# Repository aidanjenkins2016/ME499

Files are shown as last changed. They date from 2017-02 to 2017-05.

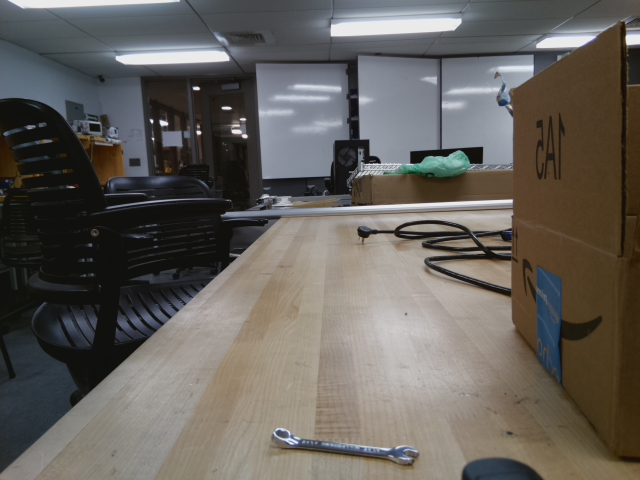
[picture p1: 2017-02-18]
Image Processing Test/output.jpg

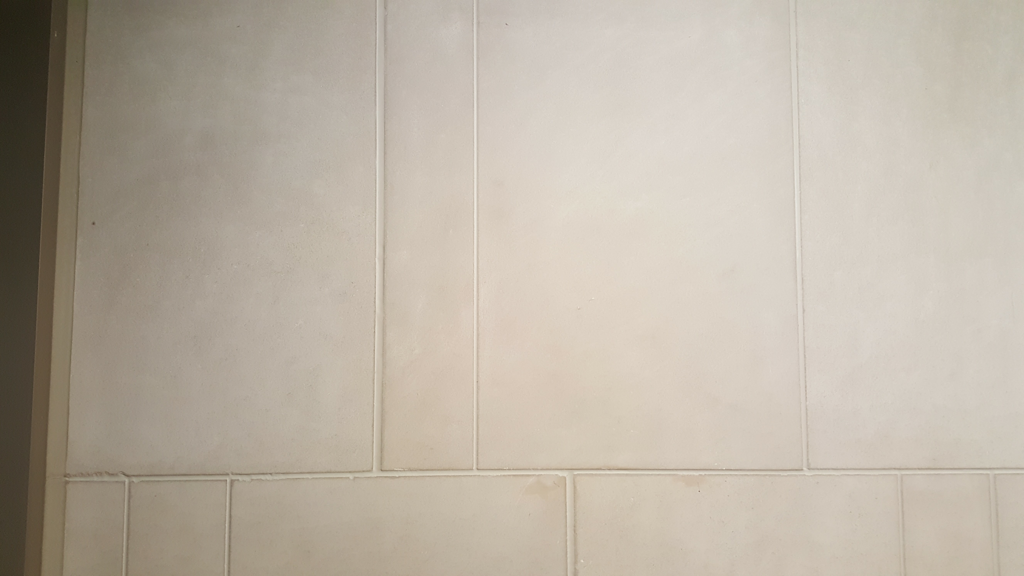
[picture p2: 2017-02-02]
Test Images/20170127_183603.jpg

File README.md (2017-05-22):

# ME499: Exploring Autonomous Vehicles
Repo for our ME499 Exploring Autonomous Vehicles Project

The bulk of this repo contains files for our computer vision project. This projects relies on a 1:10 scale RC buggy outfitted with a Raspberry Pi 3B and Pi camera for navigating hallways. We seek to build on our prior expereince with autonmous driving, using GPS and compass data, by exploring computer vision and machine learning algorithms.

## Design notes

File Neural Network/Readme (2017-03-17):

The neural network code is found here. The Doge_Net code is a test implementation that attempts to identify dogs and cats. This allows for development and debugging since we currently do not have training data for the Tech Hallways.

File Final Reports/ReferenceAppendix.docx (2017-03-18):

Reference Appendix:

Included are relevant links for understanding these topics

- Setting up Raspberry Pi WiFi and SSH
  - https://www.raspberrypi.org/documentation/configuration/wireless/wireless-cli.md
  - https://www.raspberrypi.org/documentation/remote-access/ssh/
- Connecting Raspberry Pi to an enterprise network similar to Northwestern’s
  - https://www.raspberrypi.org/forums/viewtopic.php?f=36&t=44029
  - https://www.raspberrypi.org/forums/viewtopic.php?f=36&t=111100
- Cloning Raspberry Pi SD cards
  - http://lifehacker.com/how-to-clone-your-raspberry-pi-sd-card-for-super-easy-r-1261113524
- GitHub command line tutorial
  - http://product.hubspot.com/blog/git-and-github-tutorial-for-beginners
- MIT self driving car open lecture
  - http://selfdrivingcars.mit.edu/
- Udacity self driving car project
  - https://medium.com/udacity/were-building-an-open-source-self-driving-car-ac3e973cd163#.qa2c8v8vr
  - https://github.com/udacity/self-driving-car
- Arduino serial communications
  - http://www.ladyada.net/learn/arduino/lesson4.html
  - https://oscarliang.com/connect-raspberry-pi-and-arduino-usb-cable/
  - https://oscarliang.com/raspberry-pi-and-arduino-connected-serial-gpio/
  - http://www.seeed.cc/project_detail.html?id=168
- Python and OpenCV
  - http://www.pyimagesearch.com/
- http://docs.opencv.org/2.4/doc/tutorials/imgproc/imgtrans/canny_detector/canny_detector.html
- http://docs.opencv.org/trunk/d7/d8b/tutorial_py_face_detection.html
- https://pythonprogramming.net/haar-cascade-face-eye-detection-python-opencv-tutorial/
- Ubuntu
  - http://www.pyimagesearch.com/2015/07/20/install-opencv-3-0-and-python-3-4-on-ubuntu/
- Mac
  - http://www.pyimagesearch.com/2015/06/15/install-opencv-3-0-and-python-2-7-on-osx/
- Raspberry Pi
  - http://www.pyimagesearch.com/2016/04/18/install-guide-raspberry-pi-3-raspbian-jessie-opencv-3/
- Research and Neural Networks
  - http://blog.davidsingleton.org/nnrccar/
  - https://www.youtube.com/watch?v=O8BXapqL5lA
  - https://github.com/hamuchiwa/AutoRCCar

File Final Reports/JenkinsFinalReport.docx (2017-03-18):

Aidan Jenkins

March 17, 2017

ME499

Autonomous Vehicle 499: Winter 2017

Advisor: Nick Marchuk

Introduction

This second quarter of work on the autonomous vehicle project was completed with Ryan Yu and we sought to expand on lessons learned from Fall 2016 and investigate more popular and sophisticated technologies. In this stage of the project computer vision and machine learning technologies were explored. The goal of the project was to have the car navigate the main loop on the second floor of the Technological Institute at Northwestern University (Tech). This was selected because of its proximity to the Mechatronics Lab in the Ford building, its large hallways with distinct tile patterns, and absence of fire doors. A second chassis was acquired so work could be performed without dismantling the car from the Fall. An additional goal of this quarter’s project was to keep hardware costs down. Machine learning and computer vision algorithms are computationally expensive, however we wanted to maintain accessibility for this project, so popular hobby components were used. This report will document the steps taken this quarter, the reasons why, and offer suggestions for future efforts. Ryan and I wished to have a demonstration at the 2017 Chicago Maker Faire in April, however that event was cancelled in the second week of March.

Initial Steps

The first steps taken in this quarter of the project were to apply lessons learned from Fall 2016. Ryan and I spent the first week planning and getting a better understanding of project and what we thought it would take to complete it while being mindful of how it would fit in our schedules. The focus was on getting as much set up as possible the first half of the quarter so we could spend the rest tackling the unknowns, namely the neural network. We decided to make sure we found a location indoors to test in. Fall in Chicago was not particularly conducive to outdoor testing, particularly at the end of the quarter in December, Winter would not be any better. That is why we selected the second floor of Tech. It was safe from the elements and had regular and easily identifiable features on the floor, something we thought would be beneficial for line following and edge detection. The hallways are about 8 feet wide and form a square with over 100 feet per side. A photo of one of the hallways is shown in Figure 1. Moreover, after 7 pm the hallways were largely unoccupied so we would have ample time to test.

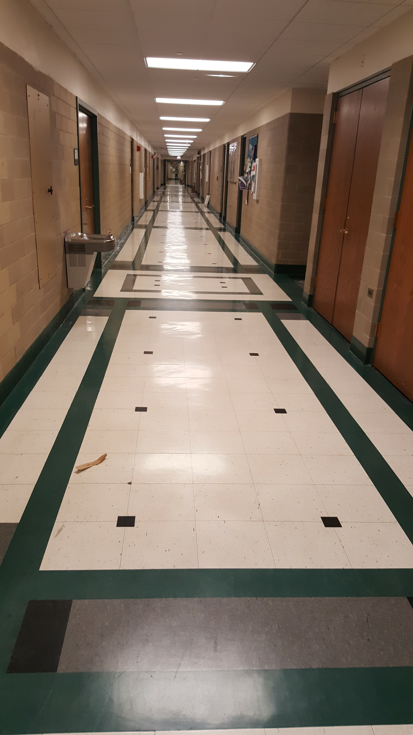
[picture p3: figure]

Figure 1 Proposed hallway for testing the car. Note linear arrangement of tiles on the floor that can be used for edge detection

Hardware selection was completed in parallel to planning, because scope and location was closely related to the quality of hardware needed. Because of the cost goals and familiarity with R/C hobby components from Fall 2016, so similar parts were used. This time a 1:10 scale buggy with 4-wheel drive was selected. Its increased ground clearance over a 1:10 “touring car” made it better suited to diving outside, or in inclement weather if we got to a point where we were testing outside. On the electronics side, hobby components, a 2.4 GHz Tx/Rx combo, brushless motor, electronic speed control (ESC), and servo were used. Similar to the Fall 2016 phase, these components were interfaced with a Teensy 3.6 microcontroller. A Raspberry Pi 3 B was selected to handle the computer vision and neural net calculations on board the car. This was the most up to date model of the Raspberry Pi featuring a 1.2GHz quad core processor, 1GB ram, and built-in wireless communication, and a dedicated graphics chip to accelerate graphics performance. This computer was selected, as opposed to a more purpose-built platform like the NVIDIA Jetson board, because of its widespread adoption, cost vs. performance, and open source support. Additionally, if the Pi had performance problems, it could stream images to a laptop or desktop.

Setup

To avoid late stage technology setbacks, we sought to set up our hardware to be tolerant to changes—we built in contingencies. One of the first orders of business was flashing a Linksys router with the open source dd-wrt firmware. This unlocks a lot of router features and would give us more options if we needed to use a server-client relationship to control the car.

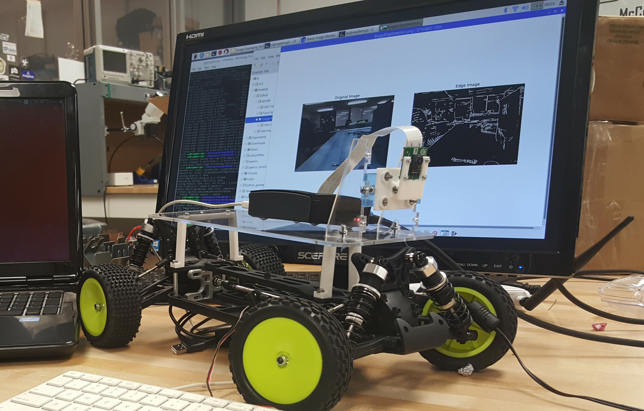
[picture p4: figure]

Figure 2 Buggy with image processing on display

The next objective was to install OpenCV, an open source image processing package. I attempted to install this in Windows 10, but this proved incredibly challenging. After two weeks of no progress, I decided I needed to move on. I created a 40GB partition on my hard drive, installed Ubuntu 16.04, and quickly installed the necessary software from the command line. Although Ubuntu can run with a lot less disk space, datasets for neural networks have gigabytes of data—it made more sense to have one larger partition than redo it later. To leverage my laptop’s graphics card for training the neural net later, I needed to install an NVIDIA driver. Initially I used the sudo apt-get command, this resulted in my computer booting, but not allowing me to log in. The latest NVIDIA driver for Linux operating systems should be downloaded from their website as a .tar file and installed.

Installing the Linux Raspbian OS on the Raspberry Pi was quickly accomplished using the New Out Of the Box (NOOBs) software from the Raspberry Pi Foundation. With Raspbian installed, downloading and installing OpenCV was trivial. For long term support and project stability Ryan installed Python virtual environments in Raspbian. This allowed us to run code using multiple versions of Python. This was important because although the newest version is Python 3.6, version 2.7 is still extremely popular and a lot of code that works on one will not work on the other. The baseline setup for hardware and software took approximately a week and a half longer than expected.

Progress

Once the software was installed, we immediately started testing OpenCV, the Pi Camera, and simply scripts in Python. We practiced operations like resizing and rotating images. To verify the install of OpenCV and better understand image processing techniques we did a “hello world” like activity with Haar cascades for face recognition. Additionally, because line following was of interest, we implemented a Canny edge detection algorithm to extract edge data from captured images. An example of an original image and an image with edge detection overlaid is shown in Figure 3. Preprocessing images is important for this project because it will greatly simplify the inputs to the neural network and lower the computation load. Eliminating “noise,” unneeded features, from the pictures before they are converted to numpy arrays allows the neural network to focus on classifying fewer elements from the images.

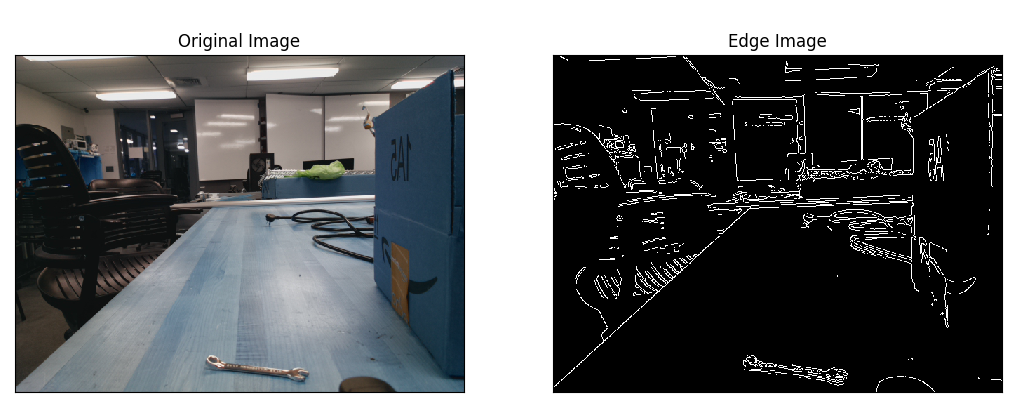
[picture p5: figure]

Figure 3 Original image captured from the Pi Camera mounted on the buggy and the Canny edge processed image

In order to get practice with neural networks, Ryan worked on a basic neural net that classified images as either containing a cat or dog. There are many ways to approach neural network design and it is difficult to understand what the exact outcome will be for the network design. This is one of the reasons why machine learning and neural networks are such popular fields, there is much more to be understood. We wanted our network to be supervised—take inputs classified by our training data code as an image paired with a steering angle and known as “good”. For a simple neural net implementation, we wanted to have an output layer with only a few nodes. In other words, for any given input, we wanted the neural net to return right, left, straight, or stop. Research into this type of implementation, however, suggested that it may not be sufficient. Information in lectures from MIT’s class 6.S094: Deep Learning for Self-Driving Cars and Udacity’s self-driving car project suggested we would need a Convolutional Neural Network

(CNN), or a Long Term-Short Term neural network to incorporate some history into the training of the model. As the amount of code and number of devices grew; four operating systems spread across three laptops and the two Raspberry Pi’s, we cloned the Pi SD cards for backup and created a GitHub repository. This way data losses would not hold us back and keep code consistent across devices. Furthermore, it allows this project to document itself, should anyone else like to work on something similar.

Conclusion

In the Fall portion of the project some parts of the code were hacked together in the last week of the quarter to make the car work. When problems arose, the code proved nearly impossible to debug. As the quarter drew to a close, we rapidly realized creating and implementing the neural network was more nuanced than we initially expected. Other courses had final projects that were taking more time away from the car project, so we focused on understanding neural networks better and how we are going to implement a more robust design in the spring instead of cobbling together something of poor quality.

The major remaining parts of the project are the data recording and classification code, building the neural network, and training the network. If the Pi cannot handle real time calculations it needs to be configured as a client that streams images to the laptop for classification and the laptop will return a steering value. The data recording code is straight forward in concept. When the car is driven in manual mode it will save images and the corresponding steering angle. When the neural network is trained, it will learn to identify the correct steering angle for what the camera is seeing. The Pi should be able to handle this using serial communication with the Teensy and storing data on its SD card, or an external USB drive. Udacity, for example, is using ROS, an open source platform for robotics, to manage the training data. This needs to be investigated as well as using a machine learning package. TensorFlow is very popular and will be much easier to use to create a CNN or a neural net with memory. Because of the difficulty of programming the more complicated neural nets in Python and the industry acceptance of TensorFlow, we strongly recommend considering it for the neural net creation. The large amount of data generated also poses a problem because of the amount of time needed to train the network. We believe the last component needed to make this project robust is creating a USB bootable version of Linux that can be run on a computer with a powerful graphics card that can accelerate training time from days to hours.

The goals originally defined for this phase of the project were ambitious and although they were not all completed, the project is better understood and well framed for success in the future. At this point, Ryan and I are very comfortable with finishing the remaining code needed to get our prototype working. Additionally, we will have more time to devote to the project. Ryan has finished taking classes and is doing some travelling. I am only enrolled in one class and working in the mechatronics lab. It would have been very satisfying to finish the project this quarter, however we are well set up for next quarter and are looking forward to completing the project the right way.

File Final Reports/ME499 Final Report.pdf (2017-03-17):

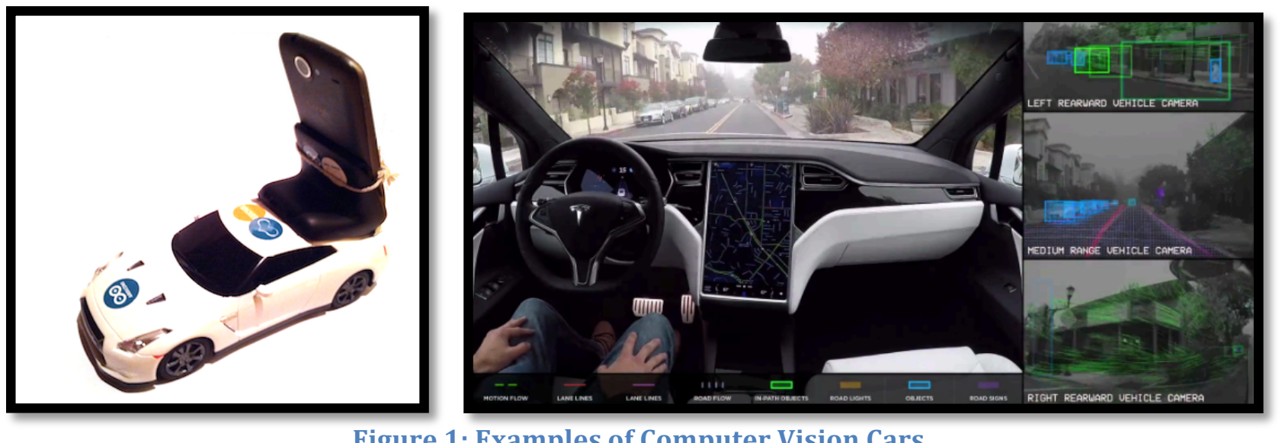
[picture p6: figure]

Yu 1

Siyuan Yu
ME499
Nick Marchuk

Building a Computer Vision Based Autonomous Vehicle

I. Abstract

This quarter, I worked with Aidan Jenkins to build a vehicle capable of computer vision based autonomous navigation. The main goals of this project were to learn how to use OpenCV, neural networks, the raspberry pi 3, and the pi camera in order to build an RC vehicle that could drive itself. Through the mistakes that were made and knowledge that was gained from the previous quarter, we managed to plan out our goals more realistically and meet the deadlines that we set out to achieve this quarter. Overall, we successfully downloaded and implemented OpenCV for image processing, began developing a neural network for computer vision learning, and built a custom RC car platform that can interface with the Raspberry Pi 3 and hold all of our electronics.

II. Goals and Planning

The main goal of this quarter’s project was to develop an RC vehicle capable of navigating through the hallways of tech autonomously using computer vision algorithms and a camera. From last quarter’s project, we learned that semi-autonomous navigation through GPS and IMU sensors was imprecise and not very robust. In addition, GPS navigation requires outdoor operation and does not work indoors. A computer vision approach is a much more elegant solution to this problem and has been successfully tested in projects done by students and by major companies such as Tesla and Google (see Research Appendix and Figure 1).

Figure 1: Examples of Computer Vision Cars
This computer vision approach involves combining image processing and machine learning techniques to train the vehicle to drive the way a human would by using primarily camera information. Although real autonomous vehicles rely on more than just cameras (sensor fusion from other sensors) and are based on sophisticated machine learning algorithms such as convolutional neural networks, we decided it would be interesting to see how effective a cheap Raspberry Pi based RC car can be using a standard feedforward neural network with back propagation.

After the poor scheduling of last quarter’s RC car project, one of the main focuses of this quarter was to develop a reasonable schedule and follow it as closely as possible (Figure 2). The intended goal for this quarter was to explore and develop all the hardware and software components needed to make an autonomous computer vision vehicle possible. This included downloading and learning OpenCV for image processing, learning how to use the Raspberry Pi 3 and the Pi camera, setting up our RC car to take Raspberry Pi controls, creating a neural network framework, and fabricating custom mounts for our electronics. Some of our reach goals included implementing all of our code on the Pi, training our vehicle, and testing the vehicle in tech. These goals were not met this quarter, but we have made plans to achieve these goals next quarter.

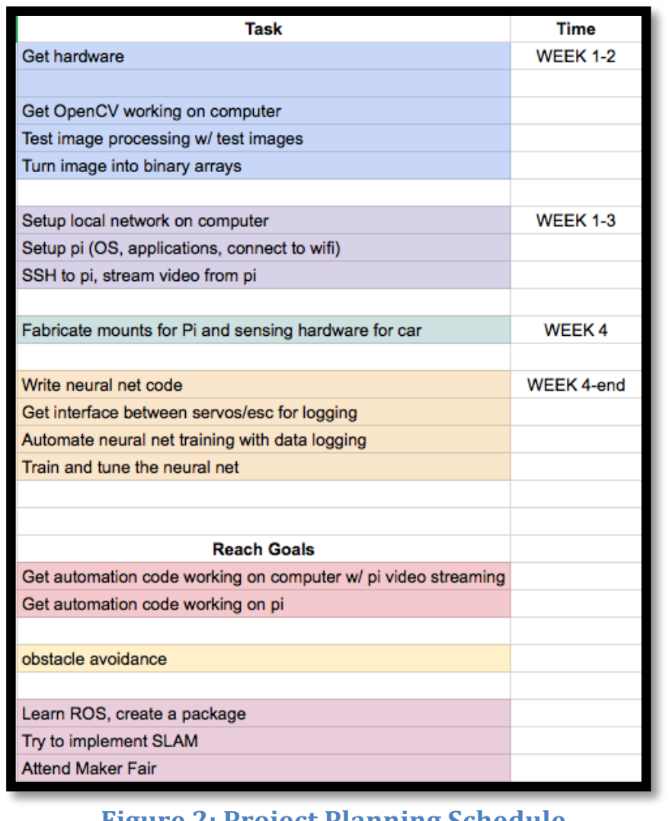
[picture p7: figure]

Figure 2: Project Planning Schedule

III. Hardware

i) RC Car

For the RC car, we decided to stick with the 4-wheel drive 1:10 scale buggy that was used in last quarter’s project. This car has great performance and adequate ground clearance for both outdoors and indoors use. In addition, the buggy has good mounting locations for our custom electronics platform. The buggy comes equipped with a 2.4 GHz TX/RX combo, an ESC, a brushless motor for throttle, and a servo for steering. Using the foundation we developed from last quarter’s project, a Teensy 3.6 is used to interface with the car’s ESC. The Teensy intercepts control inputs from either the Raspberry Pi or the RC controller and turns them into PWM inputs for the ESC (see Figure 3).

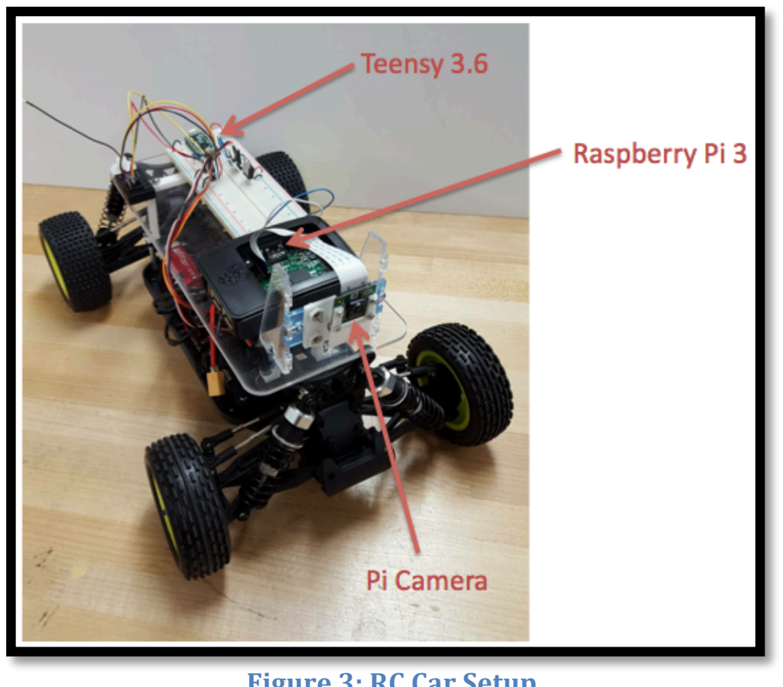
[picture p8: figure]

Figure 3: RC Car Setup
ii) Onboard Computer

We chose to use the new Raspberry Pi 3 B as our primary on board computer. We chose the Pi for its cheap price, compact size, dedicated graphics chip, and compatibility with a good selection of small but powerful camera hardware. In addition, there is lots of online support for Raspberry Pi projects (and specifically computer vision projects), which turned out to be extremely useful for us since we were first time users. Overall, the Pi directly interfaces with the camera and handles all of the image-processing and neural network computations. The Pi communicates with the Teensy using serial communication protocols and the Teensy is in charge of all the RC car control algorithms. All of this can technically be done on just the Raspberry Pi 3 alone, but due to time constraints and our previous work, we decided it would be easier for the Pi to output control commands and let the Teensy deal with the control signals.

iii) Electronics Platform

In order to hold all of these electronics, we lasercut a platform out of acrylic and 3D printed plastic supports that bolted onto the frame of the car. We also 3D printed an adjustable camera mount for the Pi camera at the front of the car. Since the camera is the only sensor that we have on the vehicle, it is extremely important that it is well mounted. It is also important that its height and angle are adjustable for distance calculations and field of view purposes.

iv) Router

In case the Raspberry Pi was not powerful enough to do the neural network computations onboard, we decided to flash a Linksys router and create a server-client network to facilitate streaming from the Pi to our laptops. This backup allows us to stream images from the Pi and perform the necessary computations on our laptops on the go. This type of streaming setup introduces delay into the system, but is a good backup to have in case all the computations cannot be performed onboard. This networks is also helpful for debugging and training purposes.

IV. Software

i) OpenCV

One of the most important goals of this project was to learn how to download, setup, and use the OpenCV library. OpenCV is an open source image-processing library that provides building blocks for computer vision projects such as image filters, machine learning dataset structures, and other useful image manipulation functions. In order to develop and debug more easily, we decided to download OpenCV on the Pi and our laptops. We quickly found that downloading the library on Windows 10 was extremely difficult and that it was much easier to setup on Linux and Ubuntu. We found that PyImageSearch.com has a great series of tutorials for how to download OpenCV on the Pi as well as computers that are running Linux and Ubuntu.

After downloading OpenCV, we decided to perform a few image processing tests. The first test was to check out some of the image filters. For computer vision learning algorithms, the Canny edge detector is an extremely popular filter and helps to simplify images and recover lines of interest. We processed a few images of hallways using only a few lines of code and the OpenCV library (see Github for code). The code ran extremely quickly thanks to the efficiency of the OpenCV functions and the results showed that it could be a useful filter for our purposes (Figure 4). The utility and ease of
implementation of OpenCV filters makes it possible to simplify and distill images to their most important features before feeding them into a neural network. This makes it easier and more likely for the neural network to identify and learn patterns in the images. Because we are using a simple and conventional neural network, reducing the complexity of the input images is extremely important in increasing the likelihood of success.

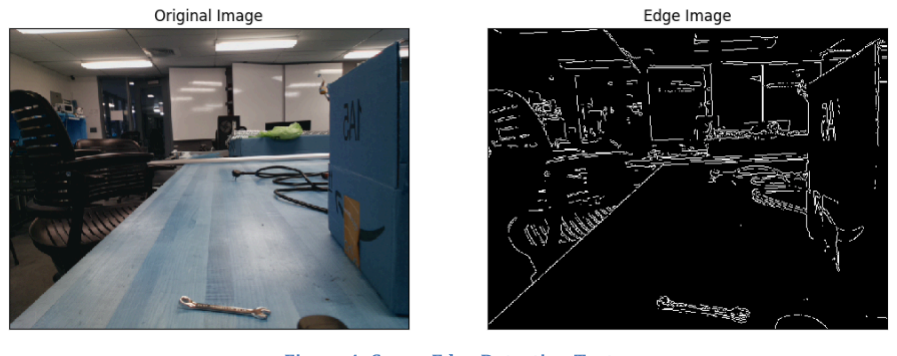
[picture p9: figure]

Figure 4: Canny Edge Detection Test

In addition, we decided to implement a simple computer vision algorithm using OpenCV as a proof of concept for our project. This was done by implementing a face detection algorithm taken from a PyImageSearch OpenCV tutorial (see Research Appendix). The algorithm uses Haar feature-based cascade classifiers to identify facial features and classify them as faces. Because of the built in features of OpenCV and the availability of training libraries online for facial detection, this code was very easy to implement and was successful in identifying faces (see Github and Figure 5). This proved that implementing a similar algorithm for identifying road features is possible using OpenCV features.

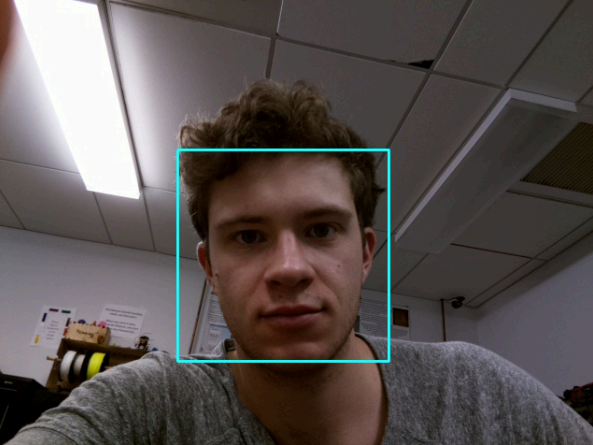
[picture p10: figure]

Figure 5: Haar Cascade Face Detection Test
ii) Python and Virtual Environments

For this project, we decided to code in Python since it is an easy to learn and widely used language. In addition, there is lots of online support for OpenCV and neural network projects in Python. In order to maintain project organization and stability, we decided to setup virtual environments for our Python 2.7 projects. These virtual environments ensure that everything that is needed to run the project files is contained in the environment and will not be disrupted by new versions of Python or other packages.

iii) Raspbian OS

On the Pi, we decided to run the very popular Raspbian OS. This system is a Linux based OS, which has a much better compatibility with the OpenCV library as mentioned earlier. The OS was setup using the New Out Of the Box (NOOBs) software provided by the Raspberry Pi foundation and was downloaded onto a 16GB memory card.

iv) Neural Network Algorithm

The neural network that we designed is a standard feedforward neural network with back-propagation. The neural network is made up of multiple layers of nodes called neurons. Each neuron is connected to all the neurons in the layer directly before and after the layer it is in. These connections all have weights and a function called an activation function. The first layer is called the input layer and has as many neurons as there are desired inputs. The last layer is called the output layer and has as many neurons as there are desired outputs. All the layers in between are called hidden layers and that’s where all the mathematical connections are made. As you train the neural network with specified input and output pairs, the weights of the neuron connections recursively change and adapt until an error function is minimized. This allows the neural network to intelligently identify complex patterns and relationships without the need of human assistance.

In our case, the input to our neural network is a flattened array of all the pixel values from an image of the road taken by the Pi camera. Our outputs for now are simply left, forward, or right steering angles (Figure 6). This methodology was taken from a very similar project done by David Singleton that was found online (see Research Appendix).

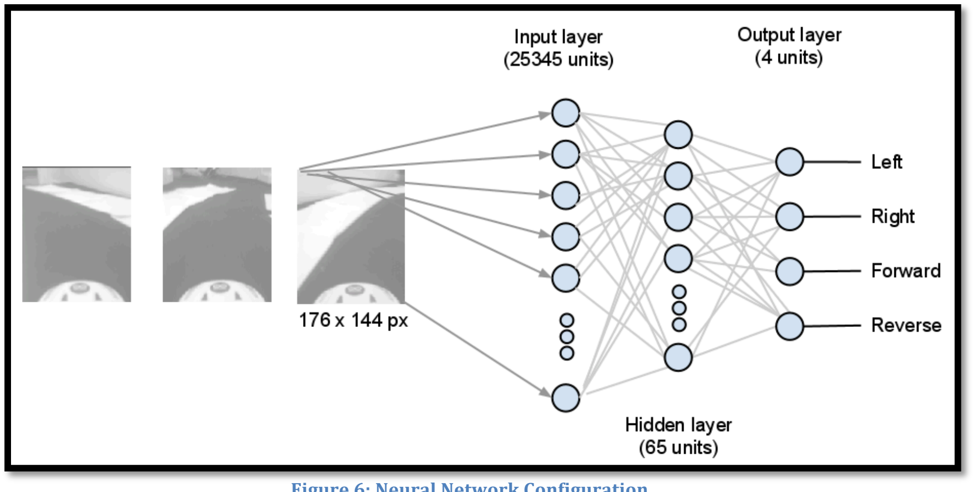
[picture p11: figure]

Figure 6: Neural Network Configuration
Once the neural network is setup, it needs to be trained by feeding the net a wide and diverse set of RC car driving images from the Tech hallways. Each image must also be labeled with a left, forward, or right steering angle (this can be expanded to however many discrete levels of steering angles we deem is necessary). A large number of training images are required to train the net to be accurate and this is determined through trial and error. For testing purposes, neural networks are typically trained on a fraction of the training data, and the remaining data is used for evaluation and verification.

During the training step, tuning must be performed as well. The tunable parameters of a standard neural network include the number of hidden layers, the number of nodes in each hidden layer, the type of activation function used, and the tolerance for the error function. In addition, the amount and quality of the training data will also affect the accuracy of the prediction results.

After the neural network is properly trained, the final weight variables are saved in a CSV file. The neural network can then be implemented onboard the RC car and perform real-time predictions based on these saved weight variables.

Currently, our training data collection method has not been designed and implemented yet. Therefore, the current iteration of the neural network is configured to take pictures of dogs and cats as inputs and output a prediction of which animal is in the picture. This was done because training datasets of cats and dogs are widely available online. Once this version of the code is debugged and working as intended, it will be easy to reconfigure the net to work for road images and output steering angles.

IV. Future Steps

As of now, the hardware for the autonomous car is almost completely ready to go. The Raspberry Pi still needs to be hooked up to power onboard the RC car.

In terms of software, there are a few things left to do. The most important thing now is to design a code that will automatically capture, save, and label road images while driving the RC car through Tech hallways. Manually labeling the massive amounts of training data that we need would be a huge undertaking, so automating this process is necessary.

For the neural network, the dog/cat classification test still needs to be debugged and tested. In addition, a function for saving the weight variables to a CSV after training still needs to be coded. After all of this is complete, the code needs to be reconfigured for our application and implemented on the Raspberry Pi.

Once all of these things are completed, the neural networks needs to be trained and evaluated using our RC car driving training data. Lots of time needs to be set aside for tuning the parameters and performance of the neural network.

V. Conclusion

Overall, this project was a great learning experience and crash course into computer vision and machine learning. In the process, I was introduced to the Raspberry Pi and became more comfortable coding in Python. In addition, I learned so much about the capabilities of OpenCV for image processing and found many useful resources on how to download the library successfully on the Pi, Mac, and Linux computers (see Research Appendix). If this neural network is successful in automating the navigation of the RC car around Tech, I think it would be interesting to design and implement a convolutional neural network for the future. This learning algorithm is more complex, more intelligent, and better suited for computer vision projects and would drastically increase our understanding of the current state of the technology.

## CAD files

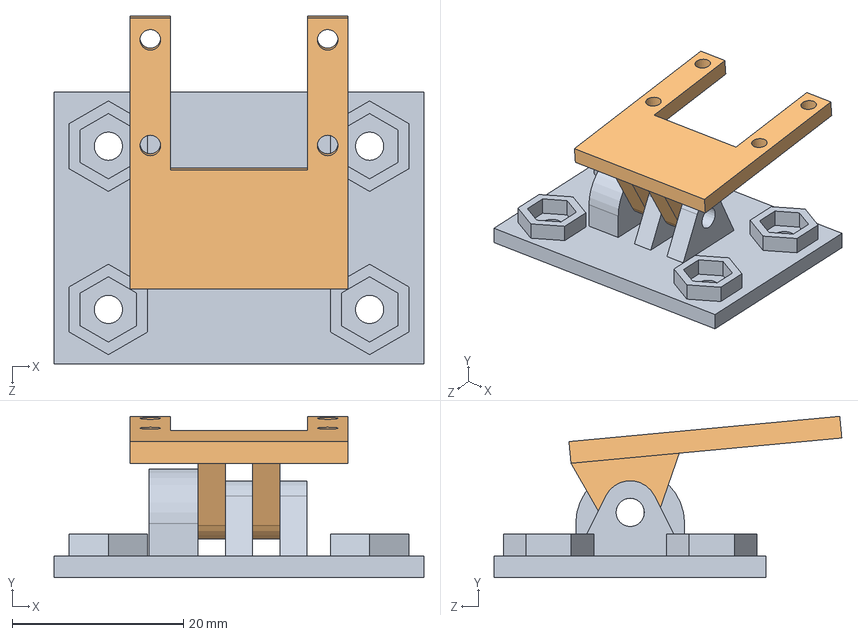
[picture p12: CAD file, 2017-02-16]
CAD Files/Camera Mount Assembly.SLDASM
43.2 x 18.8 x 40.6 mm
Camera Mount B
Camera Mount A

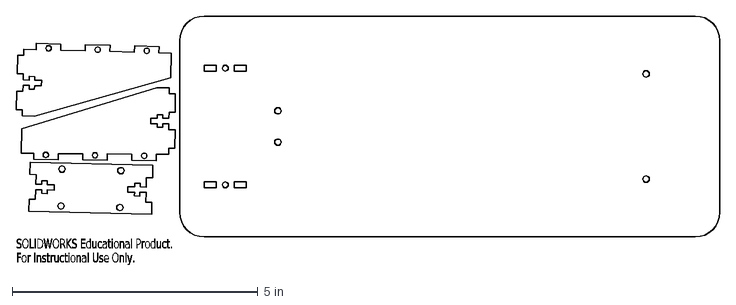
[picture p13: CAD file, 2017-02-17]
CAD Files/BuggyPartsLasercut.DXF
SOLIDWORKS Educational Product.
For Instructional Use Only.

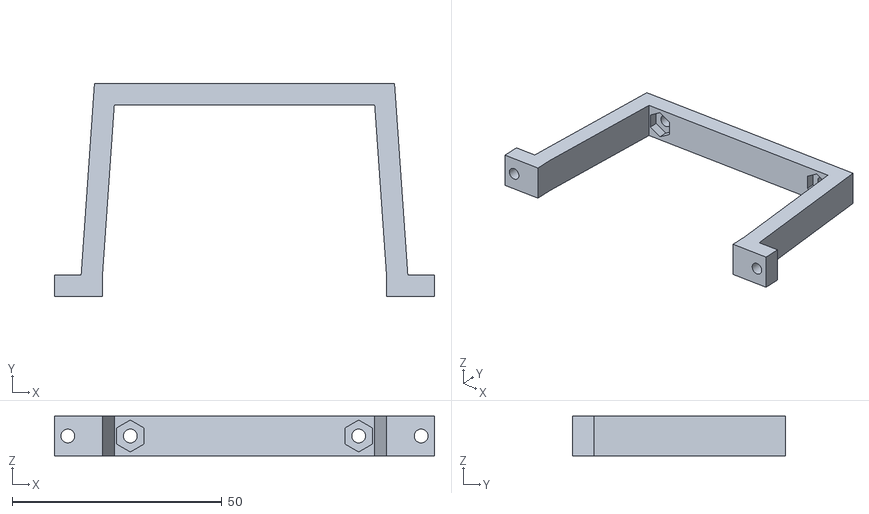
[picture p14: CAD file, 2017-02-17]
CAD Files/BuggyRearTower.STL
90.6 x 50.8 x 9.53

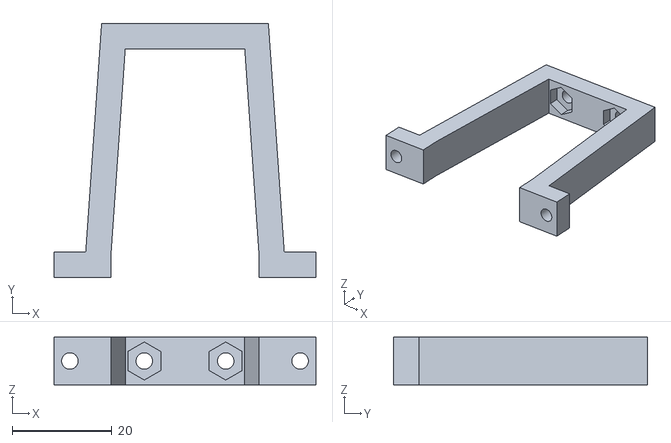
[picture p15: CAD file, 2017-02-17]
CAD Files/BuggyFrontTower.STL
52.5 x 50.8 x 9.53

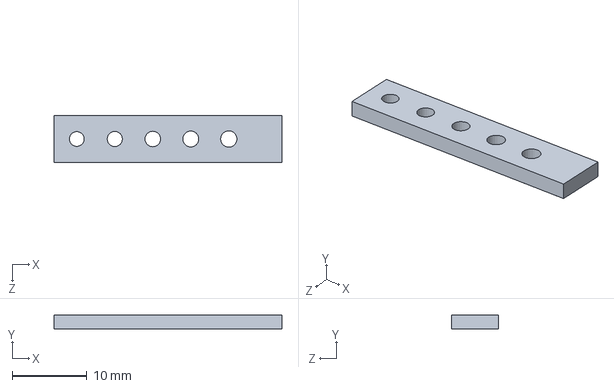
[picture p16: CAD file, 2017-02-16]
CAD Files/Hole Test Block.SLDPRT
30.5 x 1.90 x 6.35 mm

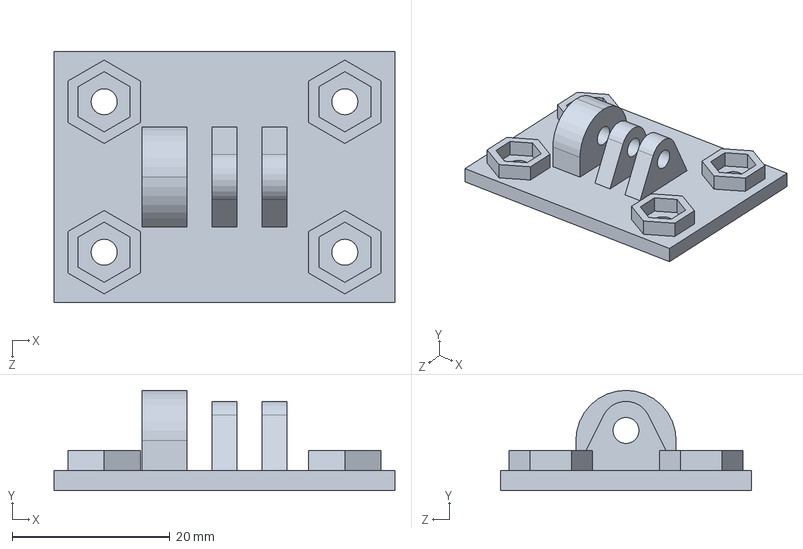
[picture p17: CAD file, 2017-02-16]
CAD Files/Camera Mount B.SLDPRT
43.2 x 12.7 x 31.8 mm

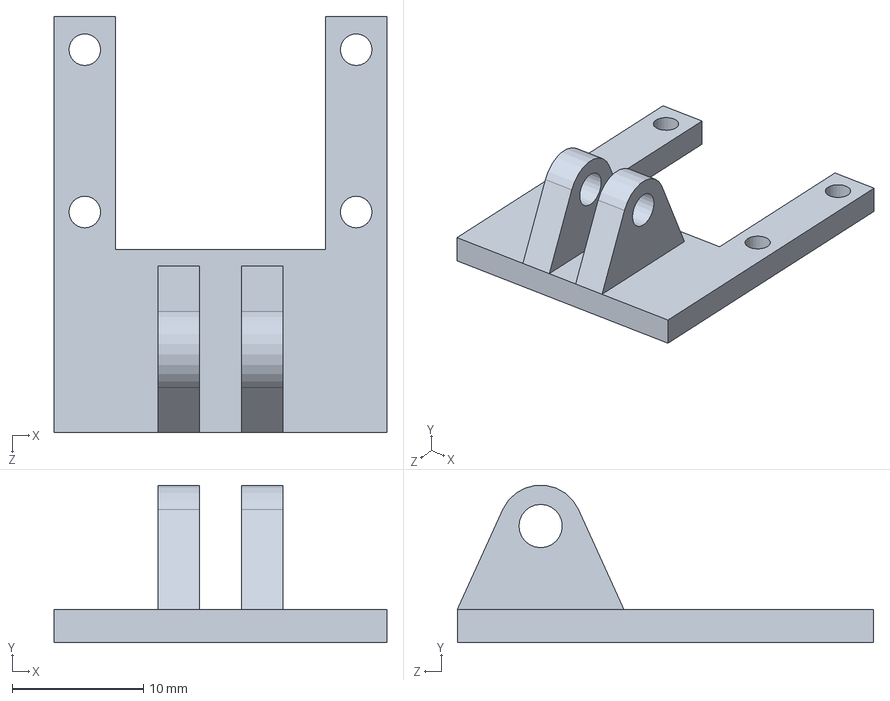
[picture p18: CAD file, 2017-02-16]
CAD Files/Camera Mount A.SLDPRT
25.4 x 12.0 x 31.8 mm

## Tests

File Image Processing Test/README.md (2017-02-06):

# ME499
Repo for our ME499 Raspberry Pi computer vision project

this is a test

testing from the pi

testing from Ryan's computer

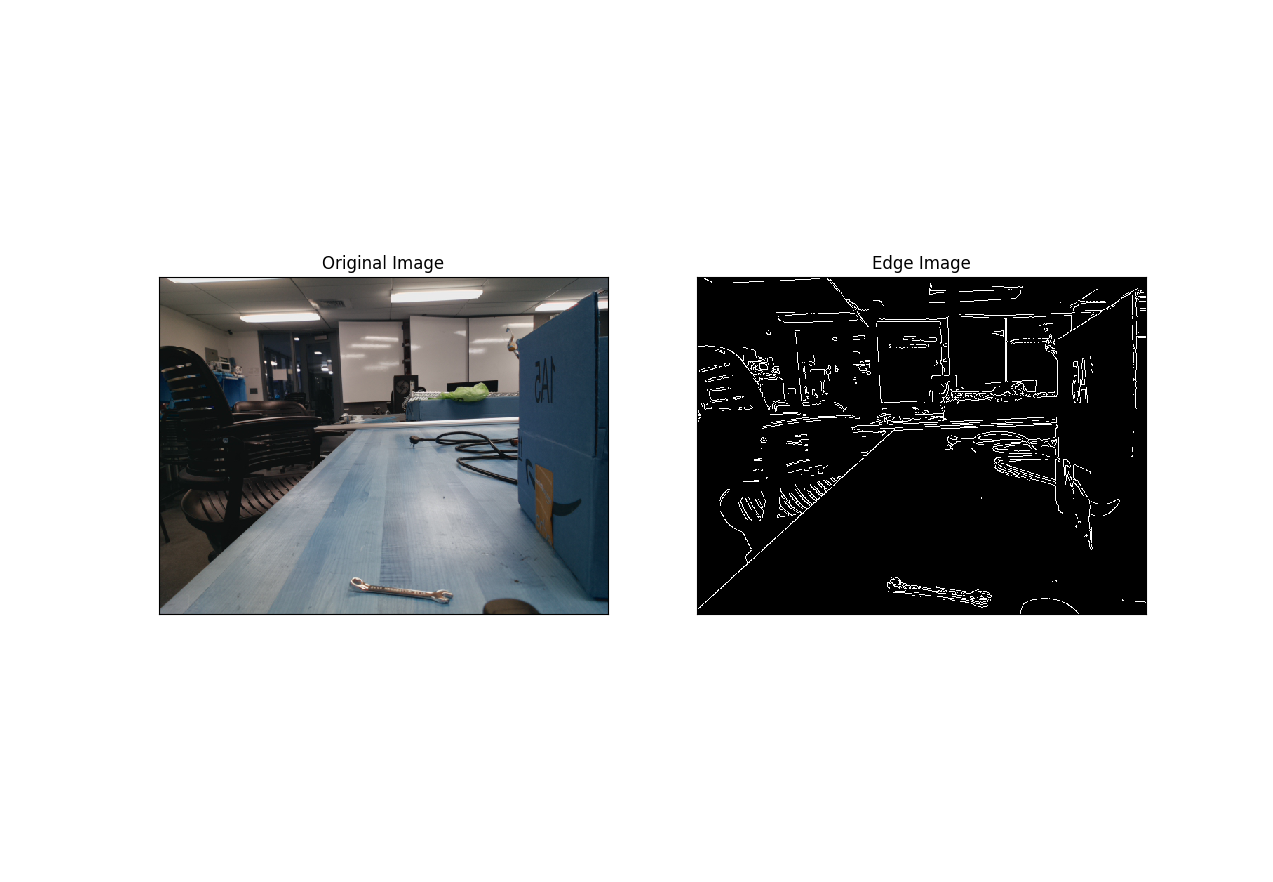
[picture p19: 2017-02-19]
Image Processing Test/BuggyEdgeDetection.png

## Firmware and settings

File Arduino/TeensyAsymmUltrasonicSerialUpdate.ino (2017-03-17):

#define outPin A21 //DAC pins are A21 and A22
#include <math.h>

//----------------------------------------------------------------------------------
//*********************************Variables****************************************
//----------------------------------------------------------------------------------

//Skew Signal Variables-----------------------------------
//--------------------------------------------------------

//Skew variables (CHANGE THESE PARAMETERS FOR TESTING)
float shape = 1; //well(1),hill(2)
float xmid1=9;
float xmid2=11;
float width1=4;
float width2=6;

//Gaussian parameters
float a = 1; //Height of Gaussian
float b1 = xmid1; //Location of shape
float b2 = xmid2; //Location of shape
float c1 = width1/6; //Width of shape 1
float c2 = width2/6; //Width of shape 2

//Normalization variables
float max1 = 0;
float max2 = 0;

//General Variables --------------------------------------
//--------------------------------------------------------

//Timer Variables
IntervalTimer myTimer1;
IntervalTimer myTimer2;

//LED and button
const int buttonPin = 35;     // the number of the pushbutton pin
const int ledPin1 =  37;      // the number of the LED pin
const int ledPin2 =  36;
boolean buttonState = true;         // variable for reading the pushbutton status
unsigned long debouncing_time = 50; //ms
volatile unsigned long last_micros;

//Other Variables
float freq=40; //vibration frequency
float Fs=10000; //sampling frequency
float Pi = 3.14159;
float skew = 0.5;
volatile int level;
float t = 0;
float t_max=1/freq;
float w1=skew*t_max, w2=(1-skew)*t_max;
volatile bool play_flag; // false == unplayed  | true == played

//Serial Communication
const byte numChars = 32;
char receivedChars[numChars];
char tempChars[numChars];  // temporary array for use when parsing

// variables to hold the parsed data
char messageFromPC[numChars] = {0};
float serial_width1 = 0.0, serial_width2 = 0.0;
boolean newData = false;

//Ultrasonic Variables------------------------------------
//--------------------------------------------------------

const int TRIG_PIN = 24;
const int ECHO_PIN = 25;

unsigned long t1;
unsigned long t2;
unsigned long pulse_width;
float cm;
float in;

// Anything over 400 cm (23200 us pulse) is "out of range"
const unsigned int MAX_DIST = 23200;


//----------------------------------------------------------------------------------
//***********************************Setup******************************************
//----------------------------------------------------------------------------------

void setup() {
  // put your setup code here, to run once:
  Serial.begin(115200);
  analogWriteResolution(12); //Max 13 bit DAC resolution, 12bit=4096 levels
  analogReadResolution(12); // reading from potentiometer for testing
  pinMode(outPin, OUTPUT); //config output pin

  // initialize the LED pins as outputs:
  pinMode(ledPin1, OUTPUT);
  pinMode(ledPin2, OUTPUT);
  
  // initialize the pushbutton pin as an input:
  pinMode(buttonPin, INPUT);

  // The Trigger pin will tell the ultrasonic sensor to range find
  pinMode(TRIG_PIN, OUTPUT);
  digitalWrite(TRIG_PIN, LOW);
  pinMode(ECHO_PIN, INPUT);

  // Setup Interrupts
  attachInterrupt(digitalPinToInterrupt(ECHO_PIN),echo_timer,CHANGE);
  attachInterrupt(digitalPinToInterrupt(buttonPin), button_debouncer, RISING);
  int interrupt_callback_time = (1 / Fs) * 1000000;
  myTimer1.begin(play_level, (int)interrupt_callback_time);
  //myTimer2.begin(print_dist, 60000); // interrupt for printing over serial

  //Setup normalization
  normalize_skew_function();
  
  delay(3000);
}

//----------------------------------------------------------------------------------
//*********************************Main Loop****************************************
//----------------------------------------------------------------------------------

void loop() {

  //check for serial data
  recvWithStartEndMarkers();
  if (newData == true) {
    strcpy(tempChars, receivedChars);
    // this temporary copy is necessary to protect the original data
    //   because strtok() used in parseData() replaces the commas with \0
    parseData();
    showParsedData();//Send received data back for integrity?
    reset_inputs(serial_width1,serial_width2);
    newData = false;
  }

  //Calculate Skew Signal
  if (play_flag) {
    t = t + 1 / Fs;
    if (t > t_max) {
      t = 0;
      
      w1= skew*t_max;
      w2= (1-skew)*t_max;
    }
    level = sample_level(t,w1,w2);
    //Serial.println(t);
  }

  //Get Position from Ultrasonic Sensor
  digitalWrite(TRIG_PIN, HIGH);
  delayMicroseconds(10); // Hold the trigger pin high for at least 10 us
  digitalWrite(TRIG_PIN, LOW);

  //Calculate distance in centimeters and inches.
  //cm = pulse_width / 58.0;
  in = pulse_width / 148.0;

  //Update Skew
  if ( pulse_width > MAX_DIST ) {
    //Serial.println("Out of range");
  } 
  else {
    //Test Case 1
    if (buttonState == true){
      skew_calc(shape,b1,c1,max1,in);
      digitalWrite(ledPin1, HIGH);
      digitalWrite(ledPin2, LOW);
    }
    //Test Case 2
    else{
      skew_calc(shape,b2,c2,max2,in);
      digitalWrite(ledPin1, LOW);
      digitalWrite(ledPin2, HIGH);
    }
    //Serial.println(skew,4);
    //delay(500);
  }
}

//----------------------------------------------------------------------------------
//**************************Function Prototypes*************************************
//----------------------------------------------------------------------------------

//Serial Functions----------------------------------------
//--------------------------------------------------------

void recvWithStartEndMarkers() {
  static boolean recvInProgress = false;
  static byte ndx = 0;
  char startMarker = '<';
  char endMarker = '>';
  char rc;

  while (Serial.available() > 0 && newData == false) {
    rc = Serial.read();

    if (recvInProgress == true) {
      if (rc != endMarker) {
        receivedChars[ndx] = rc;
        ndx++;
        if (ndx >= numChars) {
          ndx = numChars - 1;
        }
      }
      else {
        receivedChars[ndx] = '\0'; // terminate the string
        recvInProgress = false;
        ndx = 0;
        newData = true;
      }
    }

    else if (rc == startMarker) {
      recvInProgress = true;
    }
  }
}

//--------------------------------------------------------

void parseData() {      // split the data into its parts

  char * strtokIndx; // this is used by strtok() as an index

  strtokIndx = strtok(tempChars, ",");     // get the first part - the string
  //strcpy(messageFromPC, strtokIndx); // copy it to messageFromPC
  serial_width1 = atof(strtokIndx);

  strtokIndx = strtok(NULL, ",");
  serial_width2 = atof(strtokIndx);     // convert this part to a float
}

//--------------------------------------------------------

void showParsedData() {
  //    Serial.print("Message ");
  //    Serial.println(messageFromPC);
//  Serial.print("serial_width1 ");
  //Serial.print(serial_width1,4);
  //Serial.print(", ");
  //Serial.println(serial_width2,4);
}

//Matlab Input Reset--------------------------------------
//--------------------------------------------------------

void reset_inputs(float width1_new, float width2_new) {
  
  xmid1 = random(1,101);
  xmid1 = xmid1/100;
  xmid1 = xmid1 + random(7,11);

  xmid2 = random(1,101);
  xmid2 = xmid2/100;
  xmid2 = xmid2 + random(7,11);

  b1 = xmid1;
  b2 = xmid2;
  
  width1 = width1_new;
  width2 = width2_new;

  c1 = width1/6; //Width of shape
  c2 = width2/6;
  
  max1 = 0;
  max2 = 0;

  normalize_skew_function();

  buttonState = true;
  
}

//Debounce Function---------------------------------------
//--------------------------------------------------------

void button_debouncer() {
  if ((long)micros() - last_micros >= debouncing_time * 1000) {
    buttonState = !buttonState;
    last_micros = micros();
  }
}

//Skew Normalize Function---------------------------------
//--------------------------------------------------------

void normalize_skew_function(){
  
  float dx = 0.005;
  float dy1;
  float dy2;
  
  for (float x=0; x<20; x=x+dx){
    dy1 = (a*(b1-x)*exp(-sq(x-b1)/(2*sq(c1))))/sq(c1);
    dy2 = (a*(b2-x)*exp(-sq(x-b2)/(2*sq(c2))))/sq(c2);
    
    if (dy1 > max1){
      max1 = dy1;
    }
    
    if (dy2 > max2){
      max2 = dy2;
    }
 }
}

//Ultrasonic Echo Timer Function--------------------------
//--------------------------------------------------------

void echo_timer(){
  if (digitalRead(ECHO_PIN) == 1){
    t1 = micros();
  }
  else{
    t2 = micros();
    pulse_width = t2 - t1;
  }
}

//Play Level Function-------------------------------------
//--------------------------------------------------------

void play_level(void) {
  //play value on analog out pin
  //Serial.println("interrupt");
  if (!play_flag) {
    analogWrite(outPin, level);
    play_flag = true;
  }
}

//Skew Calculation Function-------------------------------
//--------------------------------------------------------

void skew_calc(int shape, float b, float c, float normalize, float x) {
  //Calculates skew based on current position and derivative of Gaussian function

  //Well
  if (shape == 1) {
    skew = -a*(b-x)*exp(-sq(x-b)/(2*sq(c)))/sq(c);
    skew = 0.5+(0.5*skew)/normalize;
  }
  //Hill
  else{
    skew = a*(b-x)*exp(-sq(x-b)/(2*sq(c)))/sq(c);
    skew = 0.5+(0.5*skew)/normalize;
  }
}

//Sample Level Function-----------------------------------
//--------------------------------------------------------

int sample_level(float t, float w1, float w2) {
  //do math to create sample
  //do we want to compute period stuff in here?
  //returning ampl level here so we can play a tone separately to
  //asynchronously compute the next output level
  float ampl;
  if (t <= w1 / 2) {
    ampl = sin( t * Pi / w1 ) * 2048 + 2048; // 4096/2=2048
  }
  else if ( (t > w1 / 2) && (t <= (w1 / 2 + w2) )) {
    ampl = sin(t * Pi / w2 + (Pi / 2) * (1 - w1 / w2)) * 2048 + 2048;

  }
  else if ( (t > w1 / 2 + w2) && (t <= w1 + w2)) {
    ampl = sin(t * Pi / w1 + Pi * (1 - w2 / w1)) * 2048 + 2048;
  }

  play_flag = false; // set flag to we know this level hasn't played

  return (int)ampl ;//needs to be int, discrete val for DAC
}

//Print Interrupt-----------------------------------------
//--------------------------------------------------------

void print_dist(void){
  //Serial.println(in,4);
}

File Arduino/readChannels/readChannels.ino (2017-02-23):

#include <Servo.h>

Servo channel1out, channel2out, channel3out;
const int ledPin = 13;
bool Serial_print = HIGH ;
volatile int autonomous_flag=0;// 0==human, 1==autonomous
volatile unsigned long timer_start1, timer_start2, timer_start3;
volatile int pulse_time1, pulse_time2, pulse_time3;
volatile int old_interrupt_time1, old_interrupt_time2, old_interrupt_time3;

//Pins
int channel1in = 10, channel2in=9 , channel3in=23 ; //input pin
int channel1out_pin = 16, channel2out_pin = 17;
int steering_center=1514, throttle_center=1498; //figure out a way to read this in


//Interrupts for rx channels
void readChannel1() {
  //ISR for input pin
  old_interrupt_time1=micros(); //get time since start of the loop
  if(digitalRead(channel1in)==HIGH)
  {
    timer_start1=micros(); //if input pin is high get time
  }
  else
  {
    if(timer_start1 != 0)
    {
      /*if the timer start is nonzero, that means you are endin a pulse
       * and need to do math to get the net time in the pulse
       */
      pulse_time1=micros()-timer_start1; //new pulse width in microseconds
      
      if(autonomous_flag==0)
      {
      channel1out.writeMicroseconds(pulse_time1);
      }
      
      timer_start1=0; //reset timer
     }
  }
  
}

void readChannel2() {
  //ISR for input pin
  old_interrupt_time2=micros(); //get time since start of the loop
  if(digitalRead(channel2in)==HIGH)
  {
    timer_start2=micros(); //if input pin is high get time
  }
  else
  {
    if(timer_start2 != 0)
    {
      /*if the timer start is nonzero, that means you are endin a pulse
       * and need to do math to get the net time in the pulse
       */
      pulse_time2=micros()-timer_start2; //new pulse width in microseconds
      
      if(autonomous_flag==0)
      {
      channel2out.writeMicroseconds(pulse_time2);
      }
      
      timer_start2=0; //reset timer
     }
  }
  
}

void readChannel3() {
  //ISR for input pin
  old_interrupt_time3=micros(); //get time since start of the loop
  if(digitalRead(channel3in)==HIGH)
  {
    timer_start3=micros(); //if input pin is high get time
  }
  else
  {
    if(timer_start3 != 0)
    {
      /*if the timer start is nonzero, that means you are endin a pulse
       * and need to do math to get the net time in the pulse
       */
            
      pulse_time3=micros()-timer_start3; //new pulse width in microseconds
      
      //control autonomous signal
      if(pulse_time3 <= 1500)
      {
        autonomous_flag=0;
      }
      else
      {
        autonomous_flag=1;
        //do nothing
      }   
      //channel3out.writeMicroseconds(pulse_time3);
      timer_start3=0; //reset timer
     }
  }
  
}


void setup() {
  // put your setup code here, to run once:
  pinMode(ledPin, OUTPUT);
  digitalWrite(ledPin, HIGH); 
  //initialize timers
  timer_start1=0;timer_start2=0;timer_start3=0;
  
  //config pins as inputs
  pinMode(channel1in, INPUT_PULLUP); pinMode(channel2in, INPUT_PULLUP); pinMode(channel3in, INPUT_PULLUP);//config read pin as input
  
  //output signal pins
  channel1out.attach(channel1out_pin); channel2out.attach(channel2out_pin); //channel3out.attach(23);
  
  //assign input interrupts
  attachInterrupt(digitalPinToInterrupt(channel1in), readChannel1, CHANGE); //assign interrupt to pin
  attachInterrupt(digitalPinToInterrupt(channel2in), readChannel2, CHANGE); //assign interrupt to pin
  attachInterrupt(digitalPinToInterrupt(channel3in), readChannel3, CHANGE); //assign interrupt to pin
  Serial.begin(9600); //serial communication

}

void loop() {
// put your main code here, to run repeatedly:

if(autonomous_flag==1)
{
  channel1out.writeMicroseconds(steering_center);
  channel2out.writeMicroseconds(throttle_center);
  //do stuff in autonomous mode

  //need another flag for learning points vs just driving around
  //look like 2 or 3 points ahead
  //create vector for point to point, 
      //check current pos often
      
      //PID steering      
}

if(Serial_print){
//print current I/O pulsewidths
Serial.print(pulse_time1);
Serial.print(" | ");
Serial.print(pulse_time2); //print pulse width in us
Serial.print(" | ");
Serial.println(pulse_time3);

delay(1000);
}

}

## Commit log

2017-02-16 Adding Camera Mount CAD Files
    [Camera Mount A.SLDPRT, Camera Mount Assembly.SLDASM, Camera Mount B.SLDPRT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]
2017-02-16 Adding New CAD Folder
2017-02-16 Added CAD Folder
2017-02-16 Added Pi Camera CAD Files
    [Camera Mount A.SLDPRT, Camera Mount Assembly.SLDASM, Camera Mount B.SLDPRT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]
2017-02-17 Adding buggy CAD Files
    [BuggyFrontTower.STL, BuggyPartsLasercut.DXF, BuggyRearTower.STL]
2017-02-18 adding test cap from camera on car
2017-02-19 Canny processing on image captured from camera mounted on buggy
    [BuggyCanny.py]
2017-02-19 Created Arduino folder and added servo and ESC code
2017-02-23 Arduino channel working on Teensy LC
2017-02-23 updated GitInstructions to include tar extraction, arduino, and teensyduino usage
2017-03-17 added teensy to COM example as code from the ME495 Haptics project
